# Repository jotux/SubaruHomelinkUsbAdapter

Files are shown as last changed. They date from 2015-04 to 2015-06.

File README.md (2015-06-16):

## Subaru Homelink mirror USB power adapter

This is a simple device to step-down the 12V used by the Homelink mirror in my Subaru to 5V and output it to a USB cable. This can technically work for any mirror that has 12V and GND.

I measured the regulator efficiency around 88% for the camera load (250-500mA).

## Schematic

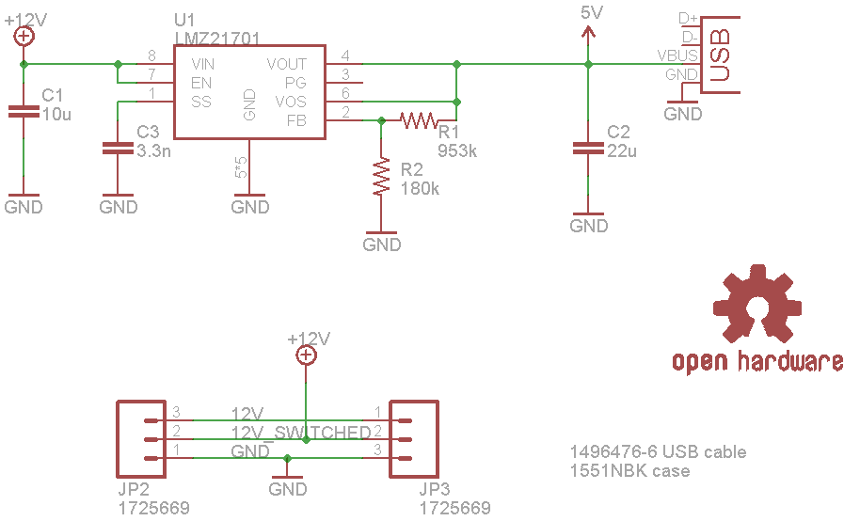
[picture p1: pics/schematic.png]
schematic


## Board

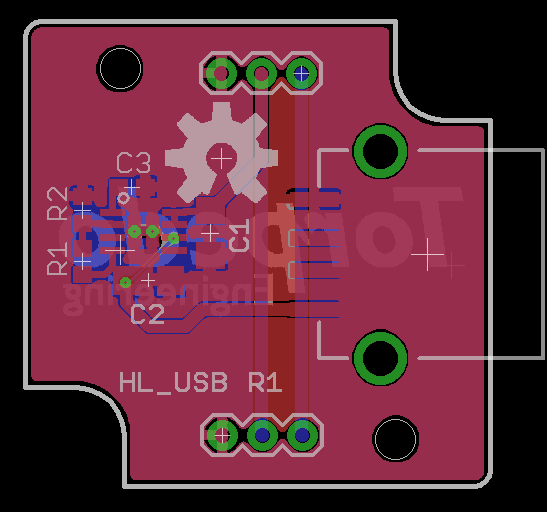
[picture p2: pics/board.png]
Board


## Installed

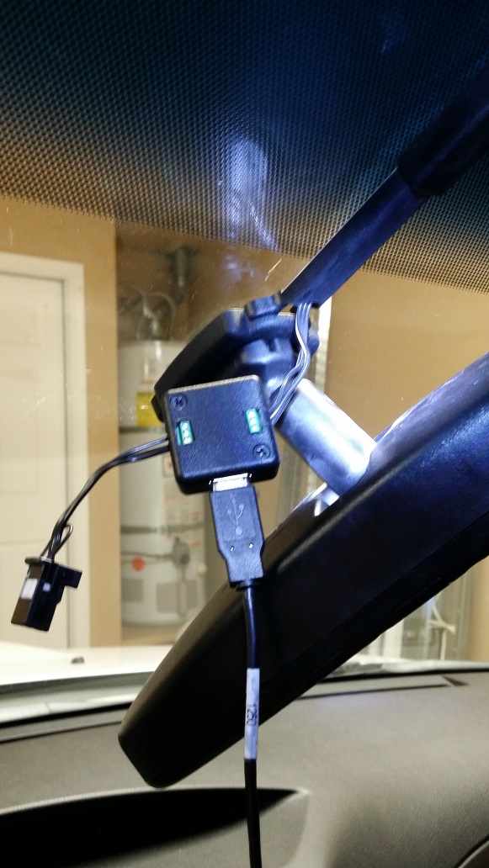
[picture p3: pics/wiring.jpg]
i1


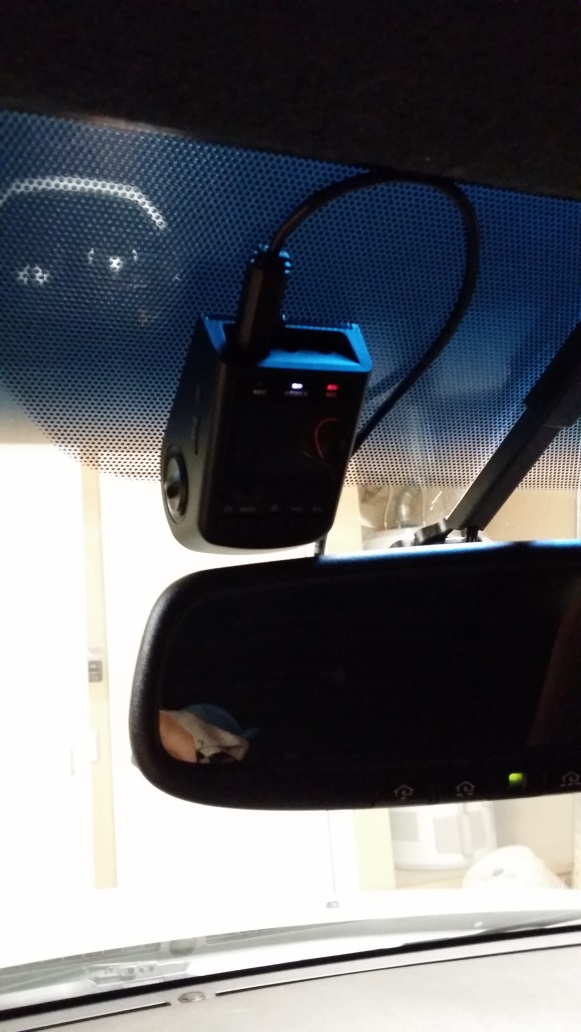
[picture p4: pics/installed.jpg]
i2


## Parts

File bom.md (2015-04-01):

## BOM

|Name |Quantity|Part Number |Distributor|
|:---:|:---:|:---:|:---:|
|C1 |1 |GRM31CR71C106KA12L  |Mouser |
|C2 |1 |GRM31CC81C226ME15L  |Mouser |
|C3 |1 |0603YC332MAT2A |Mouser |
|R1 |1 |CRCW0201953KFKED |Mouser |
|R2 |1 |ERJ-3GEYJ184V |Mouser |
|U1 |1 |LMZ21701SILT |Mouser |
|JP1 |1 |62900416021 |Mouser |
|JP2,JP3 |2 |1725669 |Mouser |

## Misc Interface

|Name |Quantity|Part Number |Distributor|
|:---:|:---:|:---:|:---:|
|N/A |1 |1496476-6 |Mouser |
|N/A |1 |1551NBK |Mouser |

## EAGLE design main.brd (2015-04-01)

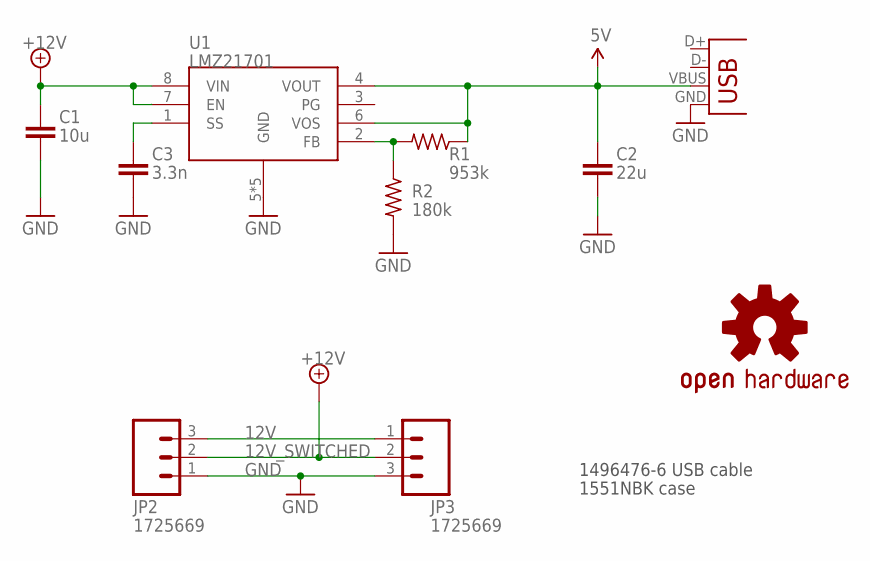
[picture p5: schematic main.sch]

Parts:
C1: 10u; C1206
C2: 22u; C1206
C3: 3.3n; C0603
JP1: 62900416021; USB-A-S-SILK-FEMALE
JP2, JP3: 1725669; 1X03
LOGO1: OSHW-LOGOL; OSHW-LOGO-L
R1: 953k; R0603
R2: 180k; R0603
U1: LMZ21701

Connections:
5V: C2.1, JP1.VBUS, R1.1, U1.4 (VOUT), U1.6 (VOS)
12V: JP2.3, JP3.1
12V_SWITCHED: C1.1, JP2.2, JP3.2, U1.7 (EN), U1.8 (VIN)
GND: C1.2, C2.2, C3.2, JP1.GND, JP2.1, JP3.3, R2.2, U1.5 (GND), U1.G1 (GND), U1.G1V (GND), U1.G2 (GND), U1.G2V (GND)
unnamed: C3.1, U1.1 (SS)
unnamed: R1.2, R2.1, U1.2 (FB)

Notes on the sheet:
1496476-6 USB cable
1551NBK case

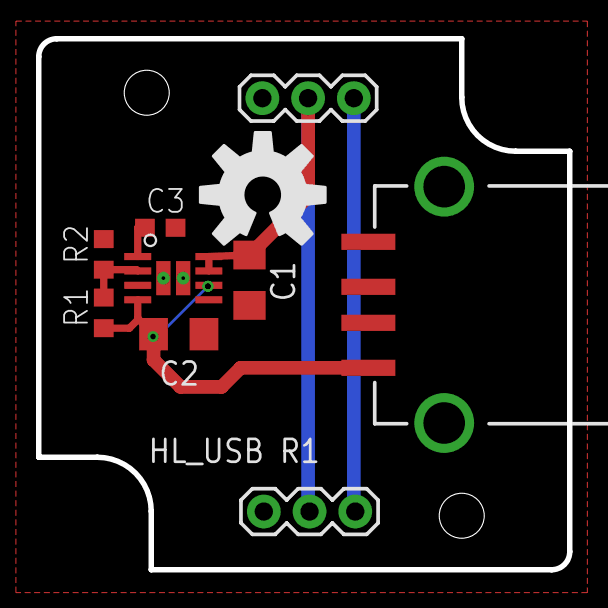
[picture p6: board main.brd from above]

Board: 2 copper layers, 29.5 x 29.5 mm, 11 parts (1 on the bottom side), 6 nets.

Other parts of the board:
U$2: LOGO

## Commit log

2015-02-11 Finished layout
    [main.brd, main.sch]
2015-02-12 Rev 0 complete, BOM and gerber added
    [main.brd, main.sch]
2015-04-01 Switch linear regulator for switching.
    [main.brd, main.sch]
2015-06-16 Remove note, since the second ground wire is 12V, enabled only when in reverse

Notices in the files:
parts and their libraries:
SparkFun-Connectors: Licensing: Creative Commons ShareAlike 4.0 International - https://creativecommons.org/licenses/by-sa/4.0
